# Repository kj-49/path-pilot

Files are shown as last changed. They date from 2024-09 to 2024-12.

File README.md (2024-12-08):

## Path Pilot

__Path Pilot__ is a self-navigating robot built on an [AVR128DB28](https://www.microchip.com/en-us/product/avr128db28) microcontroller. It was developed as part of a project during my second year of Electrical Engineering.

## PCB
As an additional aspect of our project, our group had the opportunity to design and order a PCB for our circuit. This was our first exposure to PCB design, and since it wasn't a requirement for the project, we had to learn how to use PCB design software independently. [Here](https://github.com/kj-49/path-pilot/tree/main/pcb/path-pilot-pcb) is what we came up with.

#### Schematic
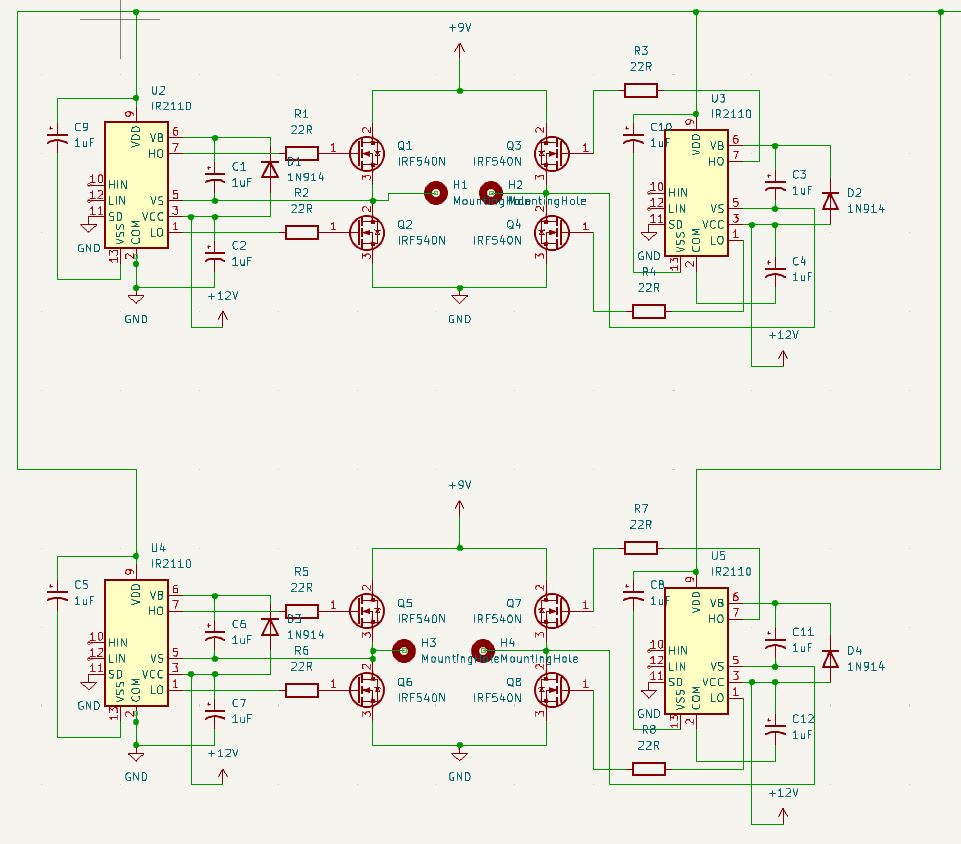
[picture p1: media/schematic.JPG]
Schematic

#### PCB Design
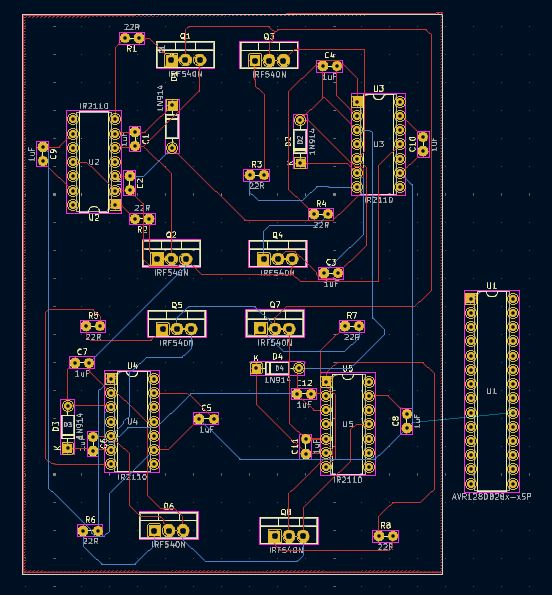
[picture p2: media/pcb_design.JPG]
PCB Design

#### PCB Render
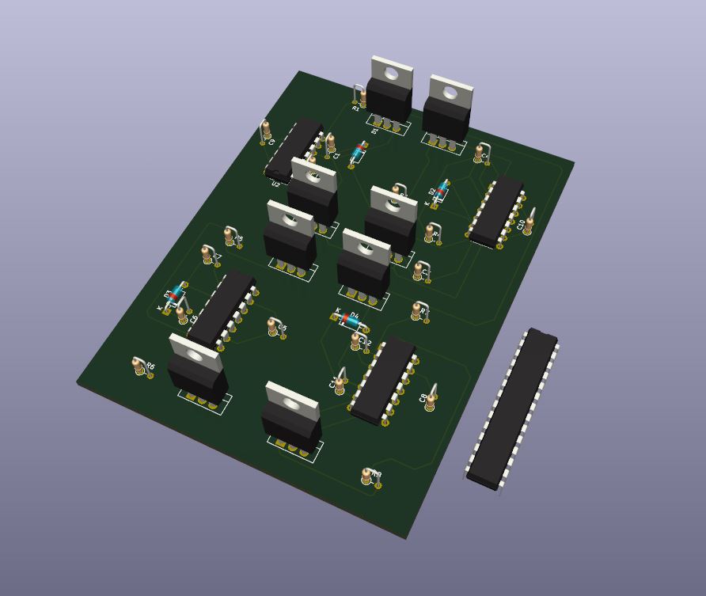
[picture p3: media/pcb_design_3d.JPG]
PCB Render

#### Final PCB
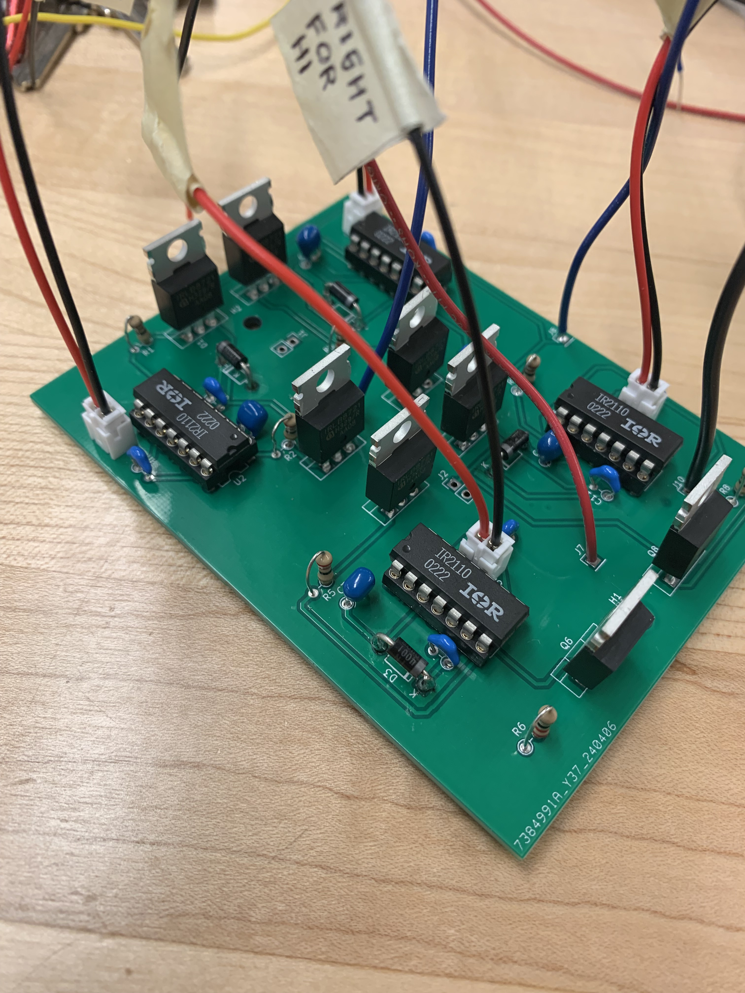
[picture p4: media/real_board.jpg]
Final PCB


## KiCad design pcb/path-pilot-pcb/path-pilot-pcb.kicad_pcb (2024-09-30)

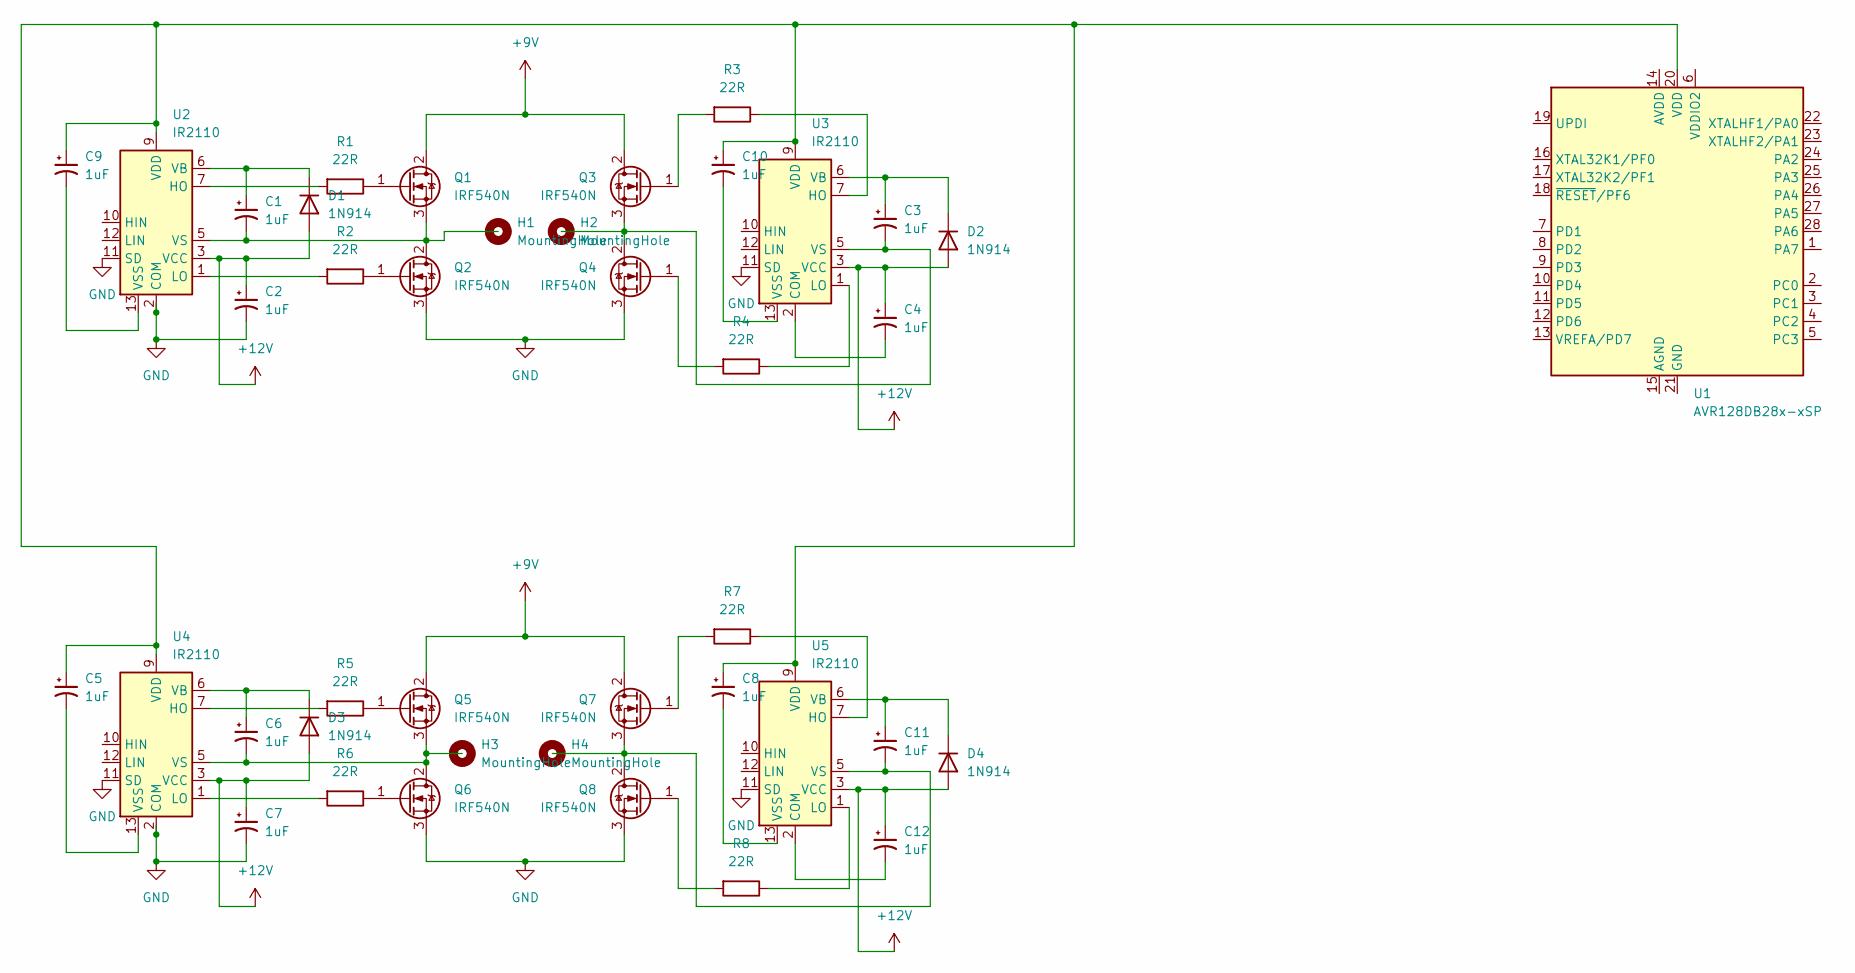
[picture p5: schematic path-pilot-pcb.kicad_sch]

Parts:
C1, C2, C3, C4, C5, C6, C7, C8, C9, C10, C11, C12: 1uF; R_Axial_DIN0204_L3.6mm_D1.6mm_P2.54mm_Vertical
D1, D2, D3, D4: 1N914; D_DO-35_SOD27_P7.62mm_Horizontal
H1, H2, H3, H4: MountingHole
Q1, Q2, Q3, Q4, Q5, Q6, Q7, Q8: IRF540N; TO-220-3_Vertical
R1, R2, R3, R4, R5, R6, R7, R8: 22R; R_Axial_DIN0204_L3.6mm_D1.6mm_P2.54mm_Vertical
U1: AVR128DB28x-xSP; DIP-28_W7.62mm
U2, U3, U4, U5: IR2110; DIP-14_W7.62mm

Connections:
+9V: Q1.2 (D), Q3.2 (D), Q5.2 (D), Q7.2 (D)
+12V: C2.1, C4.1, C7.1, C12.1, D1.2 (A), D2.2 (A), D3.2 (A), D4.2 (A), U2.3 (VCC), U3.3 (VCC), U4.3 (VCC), U5.3 (VCC)
GND: C2.2, C7.2, Q2.3 (S), Q4.3 (S), Q6.3 (S), Q8.3 (S), U2.2 (COM), U2.11 (SD), U3.11 (SD), U4.2 (COM), U4.11 (SD), U5.11 (SD)
unnamed: C1.1, D1.1 (K), U2.6 (VB)
unnamed: C3.1, D2.1 (K), U3.6 (VB)
unnamed: C6.1, D3.1 (K), U4.6 (VB)
unnamed: C11.1, D4.1 (K), U5.6 (VB)
unnamed: Q1.1 (G), R1.1
unnamed: C1.2, Q1.3 (S), Q2.2 (D), U2.5 (VS)
unnamed: Q2.1 (G), R2.1
unnamed: Q3.1 (G), R3.2
unnamed: C3.2, Q3.3 (S), Q4.2 (D), U3.5 (VS)
unnamed: Q4.1 (G), R4.2
unnamed: Q5.1 (G), R5.1
unnamed: C6.2, Q5.3 (S), Q6.2 (D), U4.5 (VS)
unnamed: Q6.1 (G), R6.1
unnamed: Q7.1 (G), R7.2
unnamed: C11.2, Q7.3 (S), Q8.2 (D), U5.5 (VS)
unnamed: Q8.1 (G), R8.2
unnamed: C5.1, C8.1, C9.1, C10.1, U1.20 (VDD), U2.9 (VDD), U3.9 (VDD), U4.9 (VDD), U5.9 (VDD)
unnamed: R1.2, U2.7 (HO)
unnamed: R2.2, U2.1 (LO)
unnamed: C9.2, U2.13 (VSS)
unnamed: C4.2, U3.2 (COM)
unnamed: R3.1, U3.7 (HO)
unnamed: R4.1, U3.1 (LO)
unnamed: C10.2, U3.13 (VSS)
unnamed: R5.2, U4.7 (HO)
unnamed: R6.2, U4.1 (LO)
unnamed: C5.2, U4.13 (VSS)
unnamed: C12.2, U5.2 (COM)
unnamed: R7.1, U5.7 (HO)
unnamed: R8.1, U5.1 (LO)
unnamed: C8.2, U5.13 (VSS)

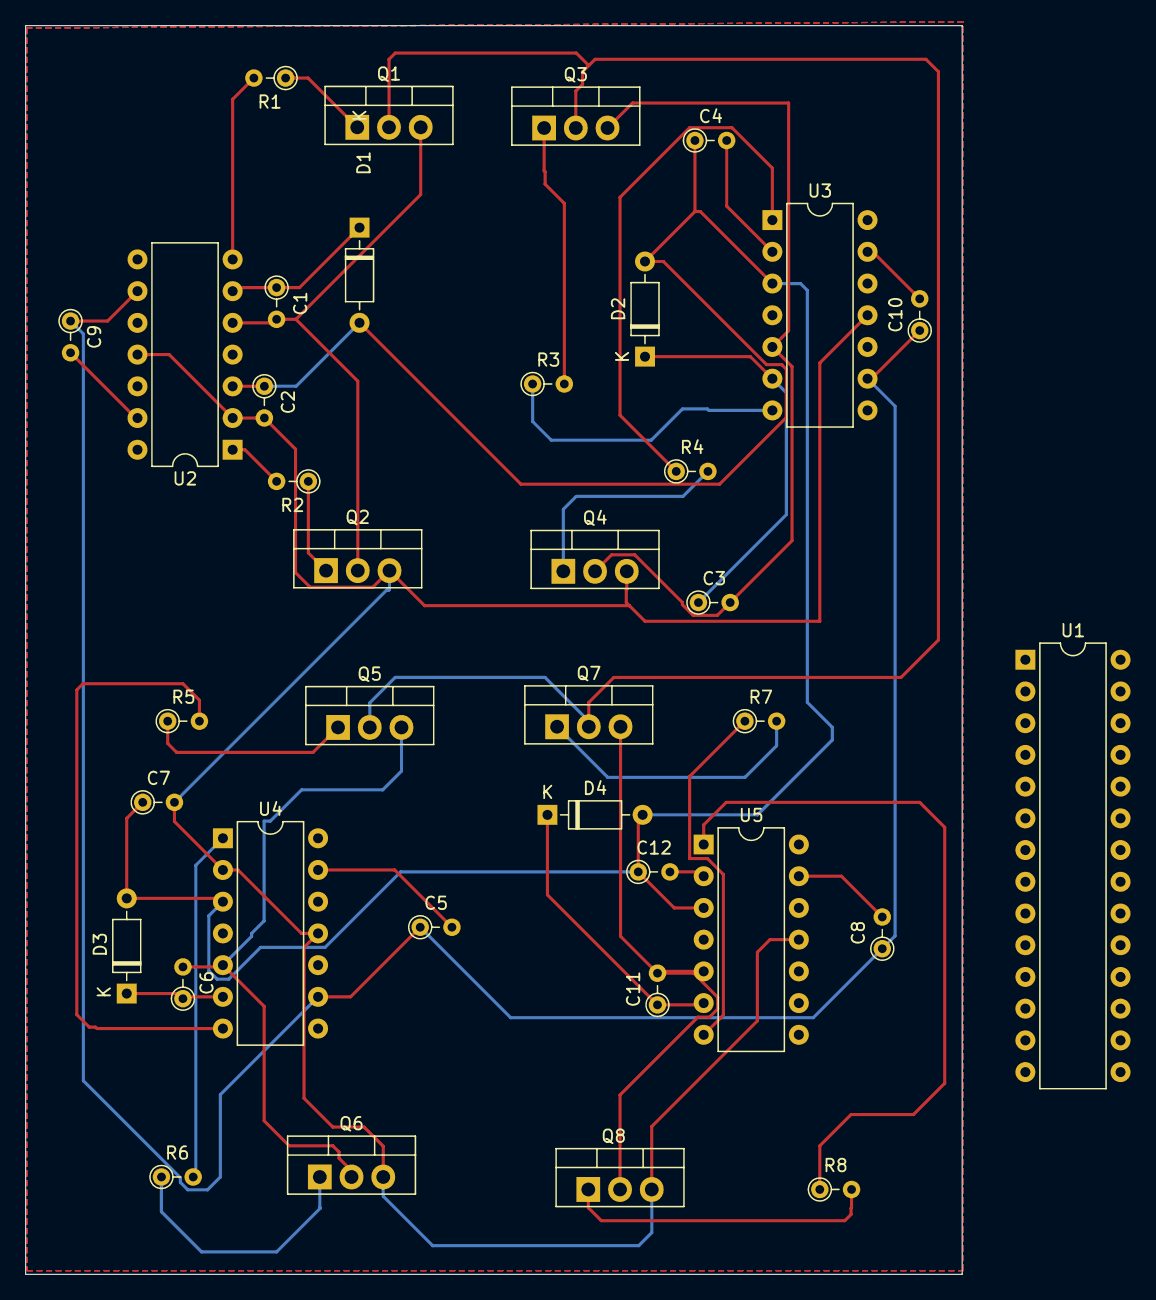
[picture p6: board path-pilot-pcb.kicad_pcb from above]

Board: 2 copper layers, 75.0 x 100.0 mm, 37 parts (0 on the bottom side), 34 nets.

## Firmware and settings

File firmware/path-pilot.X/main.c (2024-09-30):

#include "movement.h"
#include "sensors.h"
#include "avr-common.h"
#include "communication.h"

#include <avr/io.h>
#include <avr/interrupt.h>
#include <avr/delay.h>


#define DEBOUNCE_COUNT 5

void configure_pins();
void configure();
void boot_car();

int main(void) { 

    configure();

    move(DIRECTION_FORWARD);
    
    
    int obs_count = 0;
    int was_obstruction = 0;
    while (1) {
        // Check sonar reading
        if (obstruction(was_obstruction)) {
            obs_count++;
            if (obs_count < DEBOUNCE_COUNT) continue; // Skip if noise
            was_obstruction = 1;
            evade(was_obstruction);
            was_obstruction = 0; // If we return from evade we know the path is clear
        } else {
            was_obstruction = 0;
            obs_count = 0;
        }
    }
    
}

void configure_pins() {
    
    // Configure input pins
    PORTA.DIRCLR = (1 << SONAR_ECHO_A_IN_PIN);
    
    // Configure output pins
    PORTA.DIRSET = (1 << SONAR_TRIG_A_OUT_PIN) |
        (1 << L_FOR_HI_A_OUT_PIN) | 
        (1 << L_REV_HI_A_OUT_PIN) | 
        (1 << R_FOR_HI_A_OUT_PIN) | 
        (1 << RESERVED_A_PIN) |
        (1 << L_FOR_LO_A_OUT_PIN) |
        (1 << L_REV_LO_A_OUT_PIN);
    
    PORTC.DIRSET = (1 << R_REV_HI_C_OUT_PIN);
    
    PORTD.DIRSET = (1 << R_FOR_LO_D_OUT_PIN) |
        (1 << R_REV_LO_D_OUT_PIN) |
        (1 << LED_RED_D_OUT_PIN) |
        (1 << BUZZER_D_OUT_PIN);
}

void configure() {
    configure_pins();
    
    /*
     * This sets the Internal High-Frequency Clock to 1MHz.
     * This is important for our Ultra Sonic sensor measurements and conversion.
     * This will also be the clock used for our four PWM signals.
     */
    CCP = 0xd8;
    // 1MHz for clock
    CLKCTRL.OSCHFCTRLA = 0b00000000;
    // Wait for clock to change
    while (CLKCTRL.MCLKSTATUS & 0b00000001) {
        ;
    }
    
    // Initialize PWM
    TCB0_init_pwm(OPERATING_DUTY_CYCLE);
    TCB1_init_pwm(OPERATING_DUTY_CYCLE);
    TCB2_init_pwm(OPERATING_DUTY_CYCLE);
    TCD0_init_pwm(OPERATING_DUTY_CYCLE);
    

}

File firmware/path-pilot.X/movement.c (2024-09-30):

#include "movement.h"
#include "avr-common.h"
#include "sensors.h"
#include "communication.h"
#include "audio.h"
#include <avr/io.h>

// When to count obstruction in cm.
#define STOP_THRESHOLD 15 // Stop if below 10
#define GO_THRESHOLD 45 // Go if above 20
#define BUZZER_INTERVAL_MS 100
#define BUZZER_DURATION_MS 100
#define REVERSE_DURATION_MS 500

void left_wheel_set(direction_t dir);
void right_wheel_set(direction_t dir);
void TCB0_init_pwm(int perc_duty_cycle);
void TCB1_init_pwm(int perc_duty_cycle);
void TCB2_init_pwm(int perc_duty_cycle);
void TCD0_init_pwm(int perc_duty_cycle);
void set_TCB0(int state);
void set_TCB1(int state);
void set_TCB2(int state);
void set_TCD0(int state);
void set_gate(h_bridge_gate_t gate, int value);
void reverse_plus_buzzer(int ms);

int obstruction(int was_obstruction) {
    float dist = get_distance();
    /*
     * To change application state, we must be either over the GO_THRESHOLD
     * or under the STOP_THRESHOLD. The reason these number are not the same
     * is to avoid metastability where a sensor reading maybe vary ~1cm and
     * flicker our application state. This way, our app either meets these
     * requirements, or the state remains unchanged.
     */
    if (dist <= STOP_THRESHOLD) {
        return 1;
    } else if (dist > GO_THRESHOLD) {
        return 0;
    }
    return was_obstruction;
}

void evade(int was_obstruction) {
    move(DIRECTION_NONE);
    
    reverse_plus_buzzer(REVERSE_DURATION_MS);
    
    rotate_indefinite(CounterClockwise);
    
    int safe_count = 0;
    
    while (safe_count < 20) {
        // Wait for a clear path to be found
        if (!obstruction(was_obstruction)) {
            safe_count++;
        } else {
            safe_count = 0;
        }
    }
    move(DIRECTION_NONE);
    move(DIRECTION_FORWARD);
}

void move(direction_t dir) {
    left_wheel_set(dir);
    right_wheel_set(dir);
}

void rotate_indefinite(spindirection_t dir) {
    switch (dir) {
        case Clockwise:
            left_wheel_set(DIRECTION_FORWARD);
            right_wheel_set(DIRECTION_REVERSE);
            break;
        case CounterClockwise:
            left_wheel_set(DIRECTION_REVERSE);
            right_wheel_set(DIRECTION_FORWARD);
            break;
    }
}




void left_wheel_set(direction_t dir) {
    switch (dir) {
        case DIRECTION_FORWARD:
            // Turn off reverse gates
            set_gate(LEFT_WHEEL_TOP_RIGHT, 0);
            set_gate(LEFT_WHEEL_BOTTOM_LEFT, 0);
            _delay_ms(500);
            // Turn on forward gates
            set_gate(LEFT_WHEEL_TOP_LEFT, 1);
            set_gate(LEFT_WHEEL_BOTTOM_RIGHT, 1);
            break;
        case DIRECTION_REVERSE:
            // Turn off forward gates
            set_gate(LEFT_WHEEL_TOP_LEFT, 0);
            set_gate(LEFT_WHEEL_BOTTOM_RIGHT, 0);
            _delay_ms(500);
            // Turn on reverse gates
            set_gate(LEFT_WHEEL_TOP_RIGHT, 1);
            set_gate(LEFT_WHEEL_BOTTOM_LEFT, 1);  
            break;
        case DIRECTION_NONE:
            // Turn off forward gates
            set_gate(LEFT_WHEEL_TOP_LEFT, 0);
            set_gate(LEFT_WHEEL_BOTTOM_RIGHT, 0);
            // Turn off reverse gates
            set_gate(LEFT_WHEEL_TOP_RIGHT, 0);
            set_gate(LEFT_WHEEL_BOTTOM_LEFT, 0);
            break;
    }
}

void right_wheel_set(direction_t dir) {
    switch (dir) {
        case DIRECTION_FORWARD:
            // Turn off reverse gates
            set_gate(RIGHT_WHEEL_TOP_RIGHT, 0);
            set_gate(RIGHT_WHEEL_BOTTOM_LEFT, 0);
            //_delay_ms(500);
            // Turn on forward gates
            set_gate(RIGHT_WHEEL_TOP_LEFT, 1);
            set_gate(RIGHT_WHEEL_BOTTOM_RIGHT, 1);
            break;
        case DIRECTION_REVERSE:
            // Turn off forward gates
            set_gate(RIGHT_WHEEL_TOP_LEFT, 0);
            set_gate(RIGHT_WHEEL_BOTTOM_RIGHT, 0);
            //_delay_ms(500);
            // Turn on reverse gates
            set_gate(RIGHT_WHEEL_TOP_RIGHT, 1);
            set_gate(RIGHT_WHEEL_BOTTOM_LEFT, 1);  
            break;
        case DIRECTION_NONE:
            // Turn off reverse gates
            set_gate(RIGHT_WHEEL_TOP_RIGHT, 0);
            set_gate(RIGHT_WHEEL_BOTTOM_LEFT, 0);
            // Turn off forward gates
            set_gate(RIGHT_WHEEL_TOP_LEFT, 0);
            set_gate(RIGHT_WHEEL_BOTTOM_RIGHT, 0);
            break;
    }
}

void left_wheel_init_pwm(int perc_duty_cycle) {
    TCB0_init_pwm(perc_duty_cycle);
    TCB1_init_pwm(perc_duty_cycle);
}

void right_wheel_init_pwm(int perc_duty_cycle) {
    TCB2_init_pwm(perc_duty_cycle);
    TCD0_init_pwm(perc_duty_cycle);
}

void reverse_plus_buzzer(int ms) {
    // Move
    move(DIRECTION_REVERSE);
    
    int i;
    for (i = 0; i < ms; i++) {
        if (i % BUZZER_INTERVAL_MS == 0) { // Play every BUZZER_INTERVAL_MS seconds
            set_buzzer(1);
            _delay_ms(BUZZER_DURATION_MS);
            set_buzzer(0);
            i += BUZZER_DURATION_MS; // Skip some iterations since BUZZER_DURATION_MS already passed
        }
        _delay_ms(1);
    }
    
    move(DIRECTION_NONE);
}

void TCB0_init_pwm(int perc_duty_cycle) {
    
    // Set output pins MUX
    PORTMUX.TCBROUTEA &= ~(1 << 0); // TCB0 PWM on PA2
    
    TCB0_set_duty_cycle(perc_duty_cycle);
    
    TCB0.CTRLA = (0 << 0); // Disable for now timer, use DIV1 for CLK 

    TCB0.CTRLB = (1 << 4) | // Make output available on MUXed pin
                (0x7); // Use 8-bit PWM mode

}

void TCB1_init_pwm(int perc_duty_cycle){
    // Set output pins MUX
    PORTMUX.TCBROUTEA &= ~(1 << 1); // TCB1 PWM on PA3
    
    TCB1_set_duty_cycle(perc_duty_cycle);

    TCB1.CTRLA = (0 << 0); // Disable for now timer, use DIV1 for CLK 

    TCB1.CTRLB = (1 << 4) | // Make output available on MUXed pin
        (0x7); // Use 8-bit PWM mode
}

void TCB2_init_pwm(int perc_duty_cycle){
    // Set output pins MUX
    PORTMUX.TCBROUTEA &= ~(1 << 2); // TCB1 PWM on PA3
    
    TCB2_set_duty_cycle(perc_duty_cycle);
    
    TCB2.CTRLA = (0 << 0); // Disable for now timer, use DIV1 for CLK 

    TCB2.CTRLB = (1 << 4) | // Make output available on MUXed pin
        (0x7); // Use 8-bit PWM mode
}

void TCD0_init_pwm(int perc_duty_cycle){
    TCD0.CTRLB = 0x00; // Use one ramp mode

    TCD0_set_duty_cycle(perc_duty_cycle);
    
    _PROTECTED_WRITE(
            TCD0.FAULTCTRL, 
            (1 << 4) | // CMPA Enable
            (1 << 0) | // CMPA Value
            (1 << 5) | // CMPB Enable
            (1 << 1) // CMPB Value
        );
    
    // Wait for TCD to be ready
    while (!(TCD0.STATUS & (1 << 0))) {
        ;
    }
    
    // Set OSCHF as input clock
    TCD0.CTRLA &= ~((1 << 5) | (1 << 6));
    
    // We will enable inside set_TCD0 function
}

void set_TCB0(int state) {
    if (state) {
        TCB0.CTRLA |= (1 << 0); // Enable pwm waveform
    } else {
        TCB0.CTRLA &= ~(1 << 0); // Disable pwm waveform
    }
}
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

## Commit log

2024-02-03 Bit shifting now used and LED setting implemented
2024-02-04 work done on timing and ultrasonic sensor
2024-02-04 ultra-sonic sensor fully functional and outputting centimeters.
2024-02-05 USART added by untested. Circuit diagram included
2024-02-06 Distance sensing bug fixed. Needed to reset timer every time we checked distance,
    [avr-common.h, main.c, movement.c]
2024-02-16 Fixed naming in sensors.h
2024-03-01 pin changes for hbridge IC
2024-03-05 Added frequency functionality to pwm. Untested.
2024-03-08 fixed bud where pin didnt't match port.
    [avr-common.h, main.c, movement.c]
2024-03-10 pin config graphic, pwm fixes
    [avr-common.h, main.c, movement.c]
2024-03-10 Debounce added to lessen metastability. Pin configuration fixed where PORTA would be set for PORTD.
    [main.c]
2024-03-12 Motor logic tested and working. Spinning and forward movement working
2024-03-15 prototype working a responding to objects
2024-03-30 4 timer PWM implemented, not tested
2024-04-02 Fixed enable bug. All PWM working except TCD
    [main.c, movement.c]
2024-04-02 TCD conifuration bugs fixed
    [movement.c]
2024-04-02 PWM working on all 4 timers with consistent frequencies.
2024-04-03 Fixed pin diagram
2024-04-04 fixed timer bug
2024-04-05 reverse + buzzer functional
    [avr-common.h, main.c, movement.c]
2024-04-12 Fixed MCU graphic in avr-common.h
    [avr-common.h]
2024-09-30 Modified folder structure and added circuit schematics.
    [path-pilot-pcb.kicad_pcb, path-pilot-pcb.kicad_sch, photocircuit.kicad_pcb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]
2024-10-11 Added README.md (#1)
    * Create README.md
    * Added PCB section to README
